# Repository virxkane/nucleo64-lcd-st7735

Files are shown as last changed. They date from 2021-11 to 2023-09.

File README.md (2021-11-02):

# nucleo64-lcd-st7735
LCD shield for STM32 Nucleo-64 boards.

This shield is designed for connecting to STM32 Nucleo-64 boards via Arduino<sup>TM</sup> Uno V3.

**WARNING:** Although this shield can be connected to the Arduino<sup>TM</sup> UNO, it is incompatible in logic levels, so it is strictly forbidden to connect this way, otherwise this display will fail!

### Hardware
* The GMT177-01 module is used as a display and is compatible in size and pins. The display controller used is **ST7735**. The display data bus is connected to the hardware SPI. PWM can be used  to control the brightness of the screen backlight.
* Joystick K1-1504SA-03 and one button KLS7-TS6601 can be used for control. Both are connected to 3 General Purpose I/O ports via diodes.
* EEPROM memory M24C08 can be used to store user data. This IC is connected to the I2C hardware bus.
* Two LEDs are connected to ports A0(PA0) and A1(PA1).
* A separate button IT-1187-160GM-G is provided to reset the controller.

### Demo firmware
Two versions of the demo firmware have been written to work on the NUCLEO-F446RE and this shield, one using CMSIS, the other using HAL. Both are under BSD-3-Clause License.
* Using CMSIS: [nucleo-f446re-st7735spi-shield](https://github.com/virxkane/nucleo-f446re-st7735spi-shield)
* Using HAL: [nucleo-f446re-st7735spi-shield-hal](https://github.com/virxkane/nucleo-f446re-st7735spi-shield-hal)

#### Compare performance
| # |  bpp variant  | fill period, ms | transfer period, CMSIS, ms | transfer period, HAL, ms |
|---|---|---|---|---|
| 1 | fb=1, lcd=12  | 3  | 23 | 40 |
| 2 | fb=1, lcd=16  | 3  | 30 | 60 |
| 3 | fb=1, lcd=18  | 3  | 44 | 74 |
| 4 | fb=4, lcd=12  | 3  | 23 | 39 |
| 5 | fb=4, lcd=16  | 3  | 30 | 58 |
| 6 | fb=4, lcd=18  | 3  | 44 | 73 |
| 7 | fb=8, lcd=12  | 2  | 23 | 39 |
| 8 | fb=8, lcd=16  | 2  | 30 | 59 |
| 9 | fb=8, lcd=18  | 2  | 44 | 73 |
| 10 | fb=16, lcd=12 | 3  | 22 | 39 |
| 11 | fb=16, lcd=16 | 3  | 30 | 59 |
| 12 | fb=16, lcd=18 | 3  | 44 | 75 |
| 13 | fb=24, lcd=12 | 3  | 22 | 38 |
| 14 | fb=24, lcd=16 | 3  | 30 | 61 |
| 15 | fb=24, lcd=18 | 3  | 44 | 73 |

Where *fb* - frame buffer color depth, *lcd* - LCD module color depth, *fill period* - frame buffer fill period, *transfer period* - period of frame buffer transmission to LCD module.

Tests performed at SPI clock 11,25 Mbits/s.

### Schematic
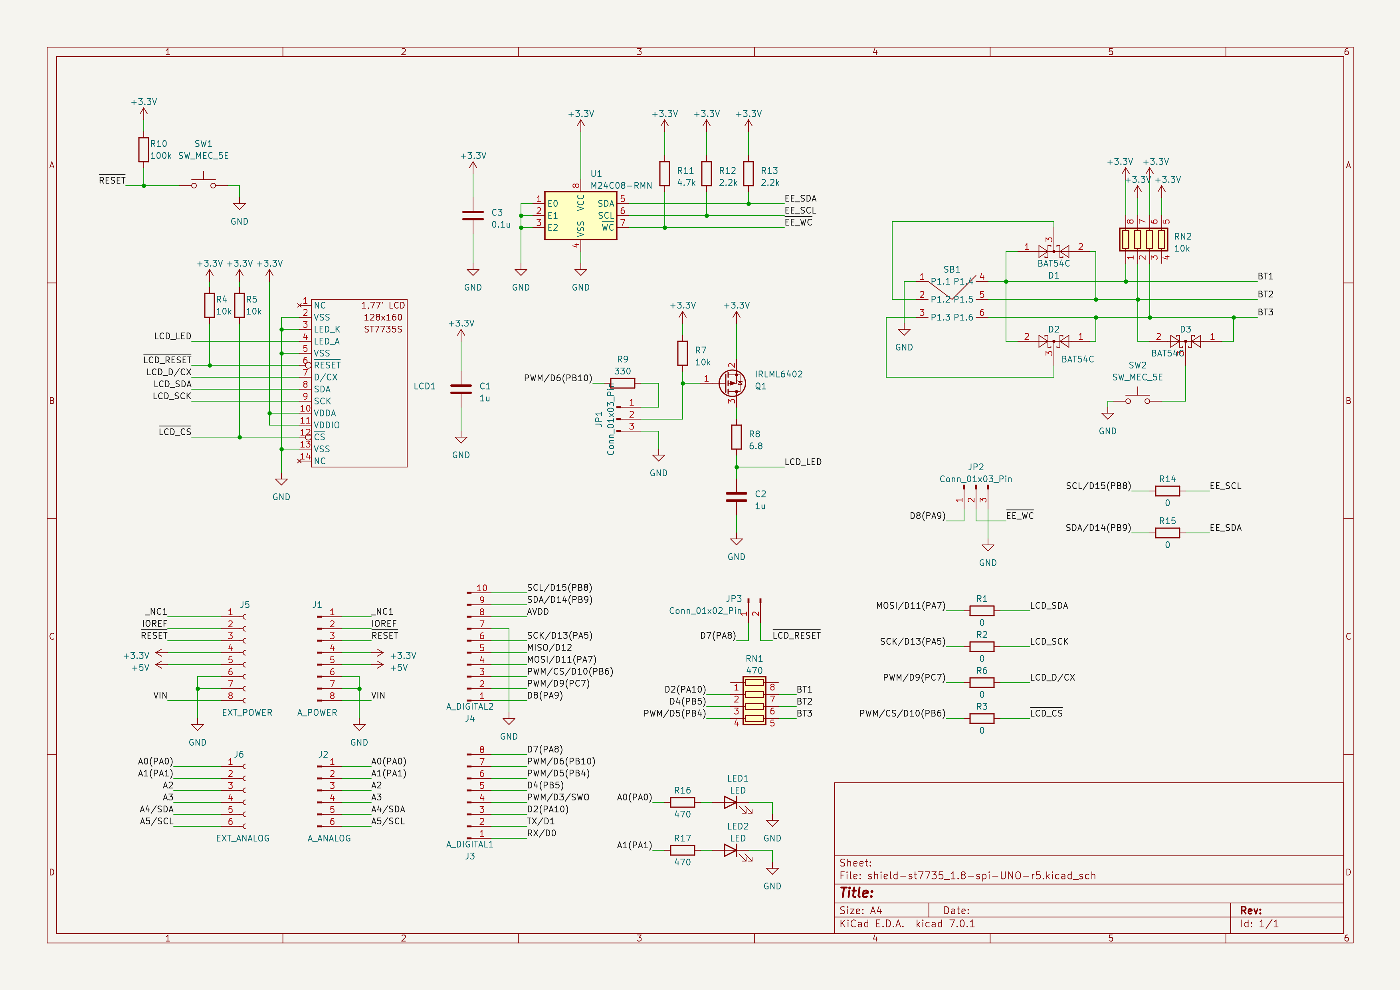
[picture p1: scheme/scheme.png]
Schematic


### Some photo
Unfortunately, there are currently no rev.4 boards, and the existing rev.3 boards have a small error - the LEDs are connected to RX/D0(PA3) and TX/D1(PA2), which by default are connected to the USART of the on-board ST-LINK/V2-1 programmer. To correct this drawback, two wire are placed on the bottom of the board to ports A0(PA0) and A1(PA1). The boards of the rev.4 are free from this drawback.

#### Front view (rev.3)
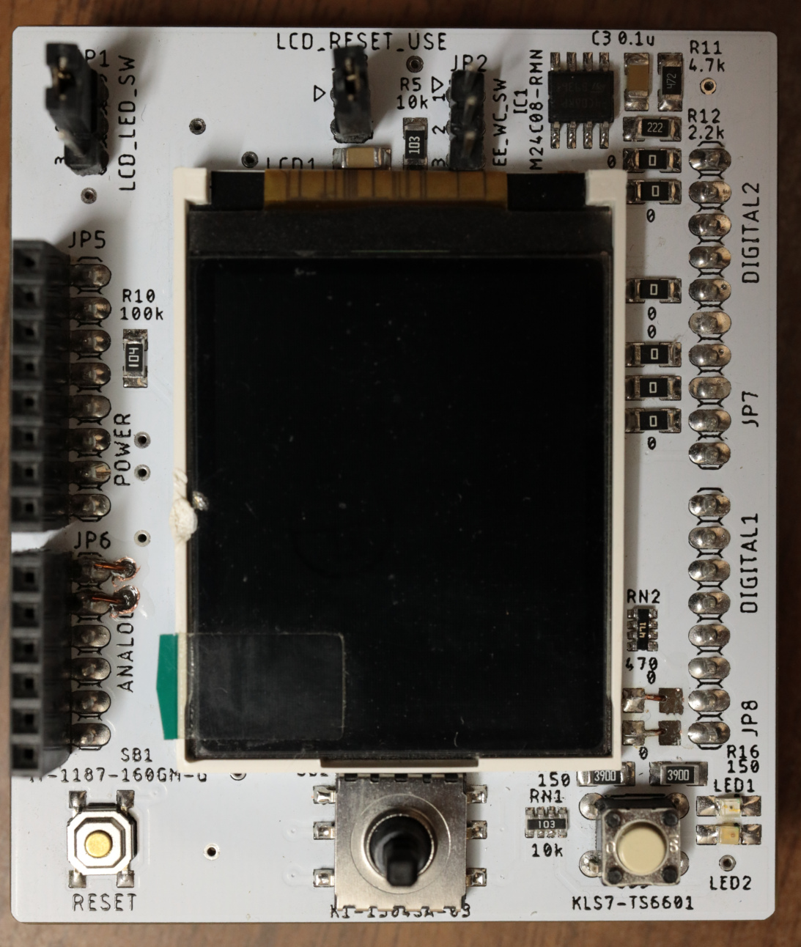
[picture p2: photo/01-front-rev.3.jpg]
Front view (rev.3)


#### Back view (rev.3)
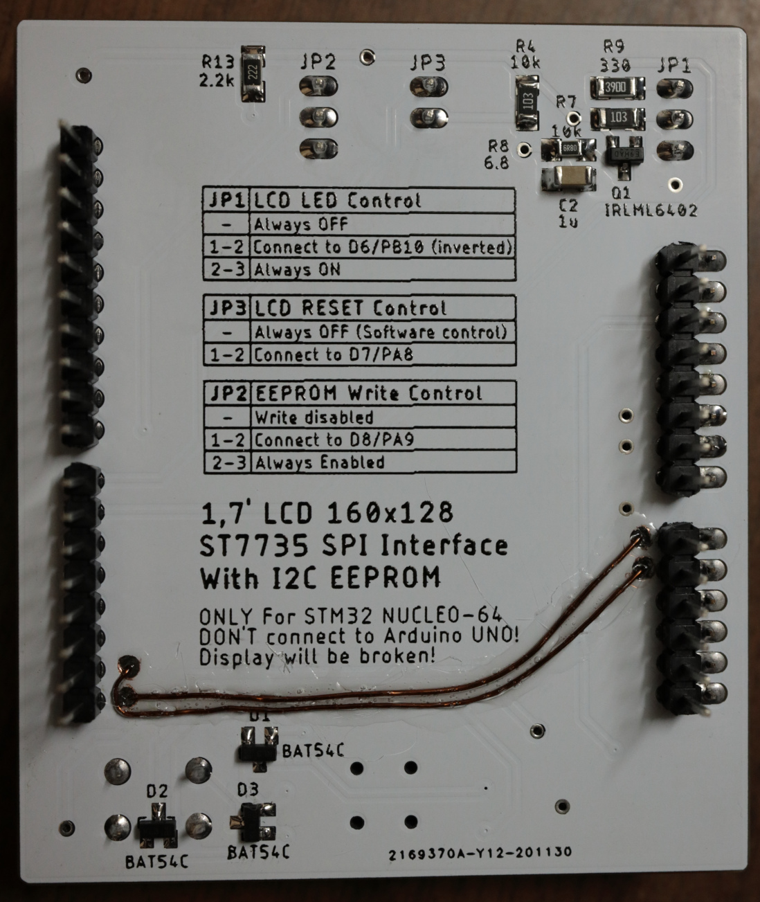
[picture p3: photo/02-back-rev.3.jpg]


#### Paired with NUCLEO-F446RE with running [demo](https://github.com/virxkane/nucleo-f446re-st7735spi-shield) (rev.3)
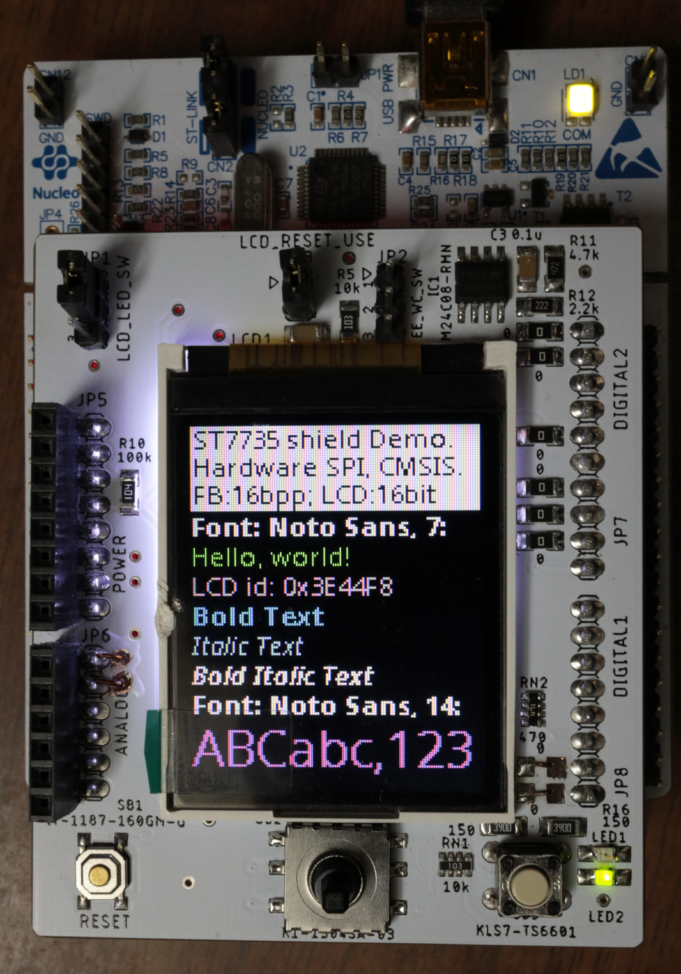
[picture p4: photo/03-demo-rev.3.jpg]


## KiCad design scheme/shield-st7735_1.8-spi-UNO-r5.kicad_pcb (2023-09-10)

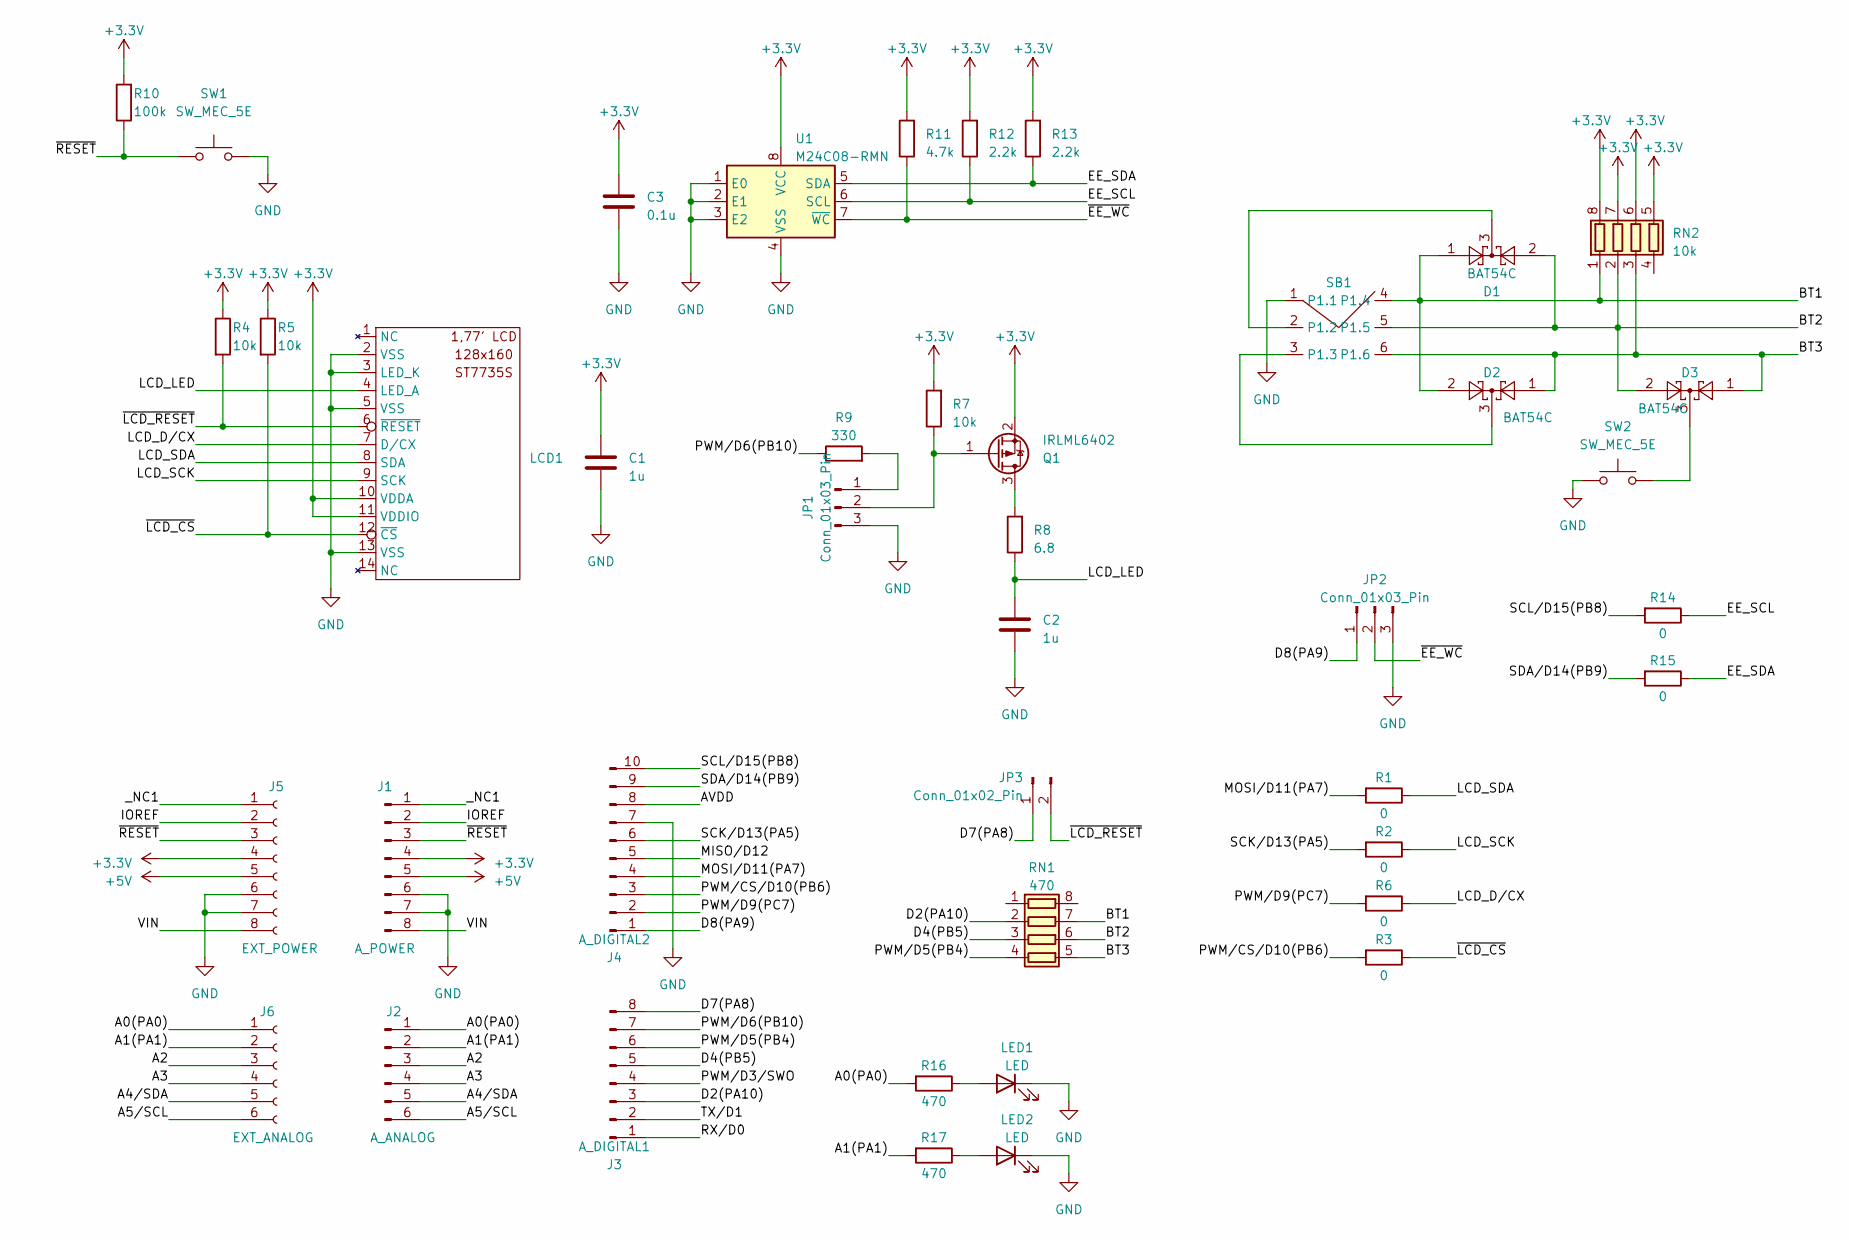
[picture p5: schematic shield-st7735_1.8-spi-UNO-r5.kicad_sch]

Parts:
C1, C2: 1u; C_1206_3216Metric
C3: 0.1u; C_1206_3216Metric
D1, D2, D3: BAT54C; SOT-23
J1: A_POWER; PinHeader_1x08_P2.54mm_Vertical
J2: A_ANALOG; PinHeader_1x06_P2.54mm_Vertical
J3: A_DIGITAL1; PinHeader_1x08_P2.54mm_Vertical
J4: A_DIGITAL2; PinHeader_1x10_P2.54mm_Vertical
J5: EXT_POWER; PinSocket_1x08_P2.54mm_Vertical
J6: EXT_ANALOG; PinSocket_1x06_P2.54mm_Vertical
JP1, JP2: Conn_01x03_Pin; PinHeader_1x03_P2.54mm_Vertical
JP3: Conn_01x02_Pin; PinHeader_1x02_P2.54mm_Vertical
LCD1: GMT177-01
LED1, LED2: LED; LED_0805_2012Metric
Q1: IRLML6402; SOT-23
R1, R2, R3, R6, R14, R15: 0; R_1206_3216Metric
R4, R5, R7: 10k; R_1206_3216Metric
R8: 6.8; R_1206_3216Metric
R9: 330; R_1206_3216Metric
R10: 100k; R_1206_3216Metric
R11: 4.7k; R_1206_3216Metric
R12, R13: 2.2k; R_1206_3216Metric
R16, R17: 470; R_1206_3216Metric
RN1: 470; R_Array_Convex_4x0603
RN2: 10k; R_Array_Convex_4x0603
SB1: K1-1504SA-03
SW1: SW_MEC_5E; SW_SPST_SKQG_WithStem
SW2: SW_MEC_5E; SW_PUSH_6mm_H4.3mm
U1: M24C08-RMN; SOIC-8_3.9x4.9mm_P1.27mm

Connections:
+3.3V: C1.1, C3.1, J1.4, J5.4, LCD1.10 (VDDA), LCD1.11 (VDDIO), Q1.2 (S), R4.1, R5.1, R7.2, R10.2, R11.2, R12.2, R13.2, RN2.5 (R4.2), RN2.6 (R3.2), RN2.7 (R2.2), RN2.8 (R1.2), U1.8 (VCC)
+5V: J1.5, J5.5
/A0(PA0): J2.1, J6.1, R16.2
/A1(PA1): J2.2, J6.2, R17.2
/A2: J2.3, J6.3
/A3: J2.4, J6.4
/A4/SDA: J2.5, J6.5
/A5/SCL: J2.6, J6.6
/AVDD: J4.8
/BT1: D1.1, D2.2, RN1.7 (R2.2), RN2.1 (R1.1), SB1.4 (P1.4)
/BT2: D1.2, D3.2, RN1.6 (R3.2), RN2.2 (R2.1), SB1.5 (P1.5)
/BT3: D2.1, D3.1, RN1.5 (R4.2), RN2.3 (R3.1), SB1.6 (P1.6)
/D2(PA10): J3.3, RN1.2 (R2.1)
/D4(PB5): J3.5, RN1.3 (R3.1)
/D7(PA8): J3.8, JP3.1
/D8(PA9): J4.1, JP2.1
/EE_SCL: R12.1, R14.1, U1.6 (SCL)
/EE_SDA: R13.1, R15.1, U1.5 (SDA)
/IOREF: J1.2, J5.2
/LCD_D/CX: LCD1.7 (D/CX), R6.1
/LCD_LED: C2.1, LCD1.4 (LED_A), R8.1
/LCD_SCK: LCD1.9 (SCK), R2.1
/LCD_SDA: LCD1.8 (SDA), R1.1
/MISO/D12: J4.5
/MOSI/D11(PA7): J4.4, R1.2
/PWM/CS/D10(PB6): J4.3, R3.2
/PWM/D3/SWO: J3.4
/PWM/D5(PB4): J3.6, RN1.4 (R4.1)
/PWM/D6(PB10): J3.7, R9.1
/PWM/D9(PC7): J4.2, R6.2
/RX/D0: J3.1
/SCK/D13(PA5): J4.6, R2.2
/SCL/D15(PB8): J4.10, R14.2
/SDA/D14(PB9): J4.9, R15.2
/TX/D1: J3.2
/VIN: J1.8, J5.8
/_NC1: J1.1, J5.1
/~EE_WC: JP2.2, R11.1, U1.7 (~WC)
/~LCD_CS: LCD1.12 (~CS), R3.1, R5.2
/~LCD_RESET: JP3.2, LCD1.6 (~RESET), R4.2
/~RESET: J1.3, J5.3, R10.1, SW1.1
GND: C1.2, C2.2, C3.2, J1.6, J1.7, J4.7, J5.6, J5.7, JP1.3, JP2.3, LCD1.2 (VSS), LCD1.3 (LED_K), LCD1.5 (VSS), LCD1.13 (VSS), LED1.1 (K), LED2.1 (K), SB1.1 (P1.1), SW1.2, SW2.1, U1.1 (E0), U1.2 (E1), U1.3 (E2), U1.4 (VSS)
unnamed: D3.3, SW2.2
unnamed: JP1.1, R9.2
unnamed: JP1.2, Q1.1 (G), R7.1
unnamed: LED1.2 (A), R16.1
unnamed: LED2.2 (A), R17.1
unnamed: Q1.3 (D), R8.2
unnamed: D1.3, SB1.2 (P1.2)
unnamed: D2.3, SB1.3 (P1.3)

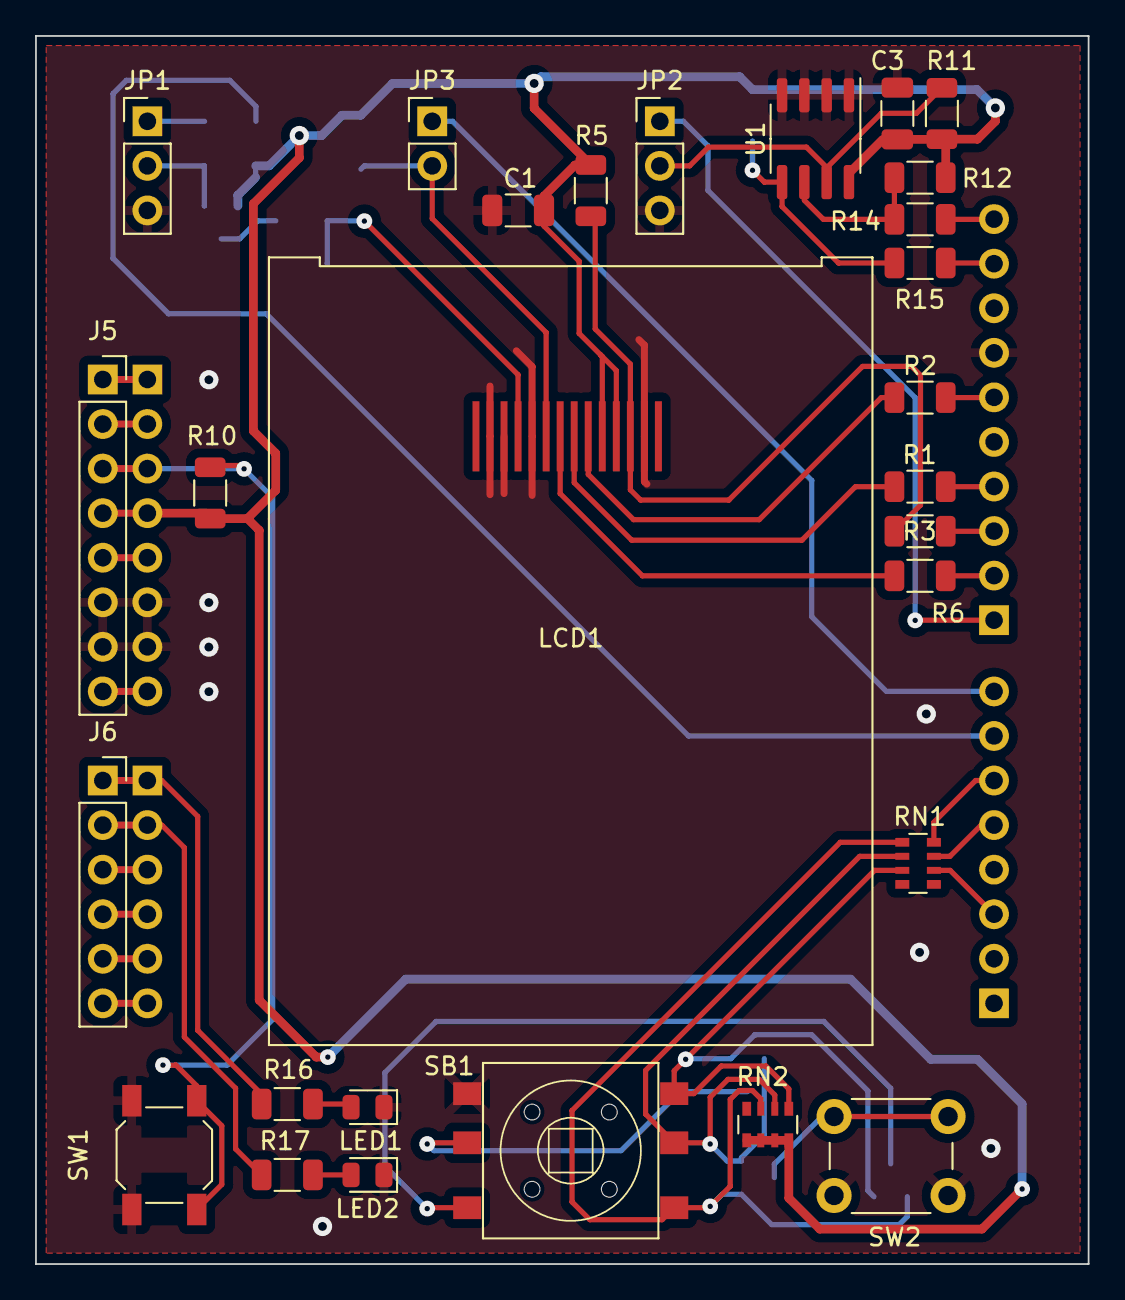
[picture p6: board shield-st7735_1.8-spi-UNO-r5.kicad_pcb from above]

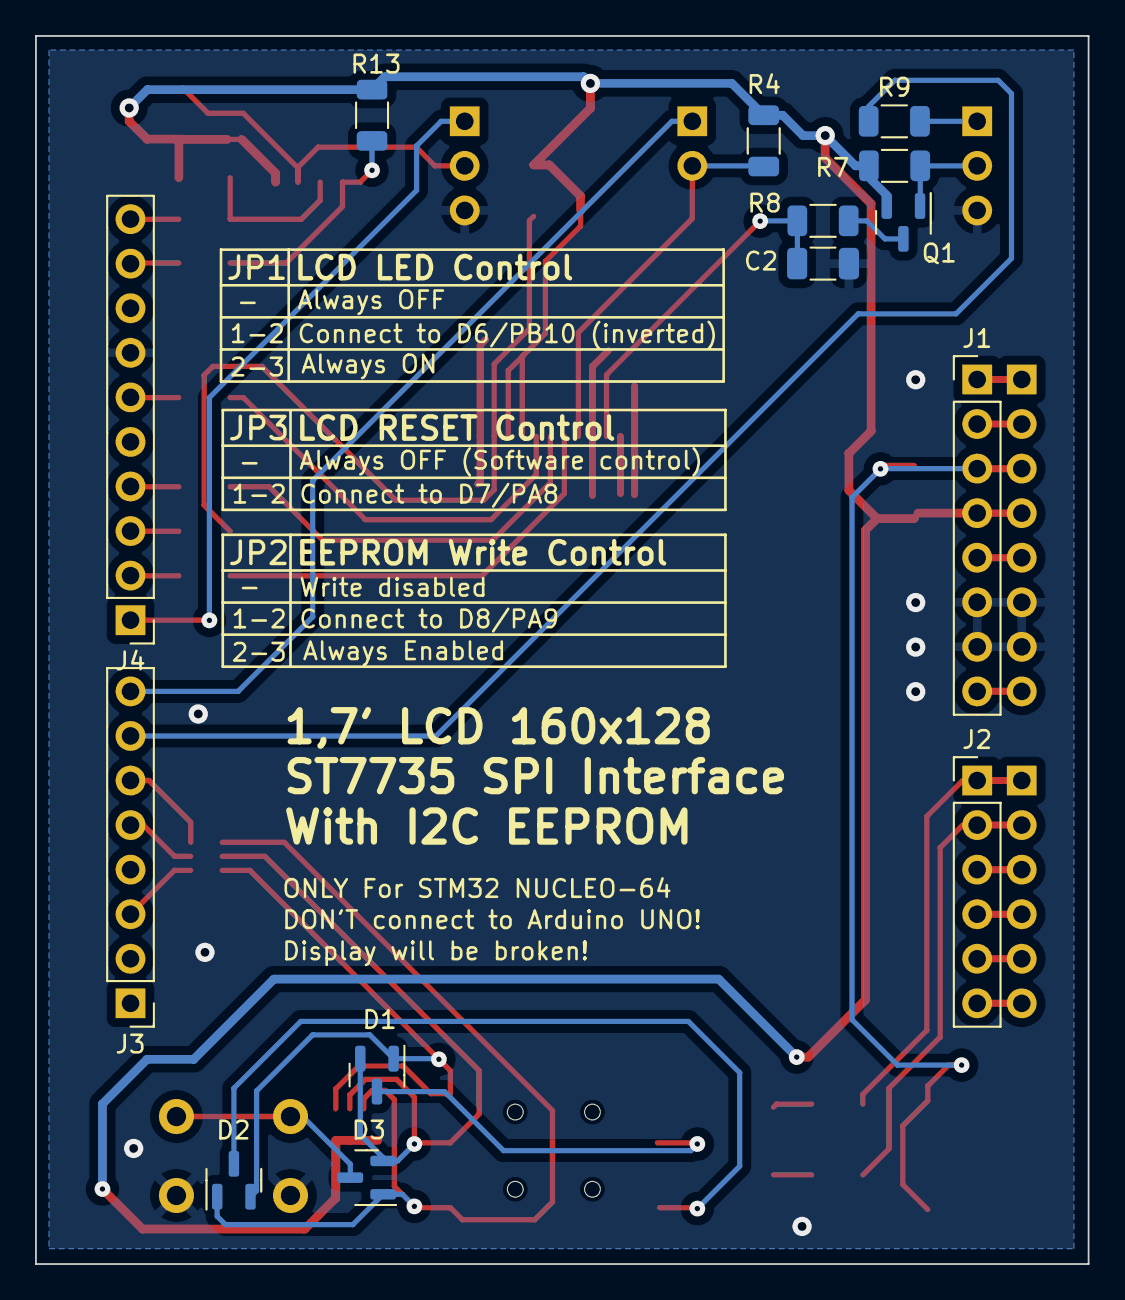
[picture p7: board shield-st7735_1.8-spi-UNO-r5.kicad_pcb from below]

Board: 2 copper layers, 60.0 x 70.0 mm, 42 parts (14 on the bottom side), 45 nets.

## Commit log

2021-11-02 Add schematic.
    [shield-st7735_1.8-spi-UNO-r4.brd, shield-st7735_1.8-spi-UNO-r4.sch]
2021-11-02 Added schematic in image format.
2023-09-10 New revision, the project has been remade in KiCAD.
    [shield-st7735_1.8-spi-UNO-r4.brd, shield-st7735_1.8-spi-UNO-r4.sch, shield-st7735_1.8-spi-UNO-r5.kicad_pcb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]
